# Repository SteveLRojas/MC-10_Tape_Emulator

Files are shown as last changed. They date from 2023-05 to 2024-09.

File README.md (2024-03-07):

# MC-10_Tape_Emulator
Unified HW and SW repository for the TRS-80 MC-10 tape emulator project.

## Dev Plan (USB Lib/FATFS)
✅- Get the STM to compile, 
- investigate funcs on top of in/out/transact to see how to use them to accomplish various operations
- Try to enumerate?
- Build bulk-only stuff?
- Implement SCSI stuff using bulk-only?
- ...??
- Glue functions?

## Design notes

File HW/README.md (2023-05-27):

# MC-10_Tape_Drive_PCB
EAGLE project for the MC-10 tape drive emulator PCB

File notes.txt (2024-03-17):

HAL: Hardware Abstraction Layer
HCD: USB Host Controller Driver
NVIC: Nested Vectored Interrupt Controller
RCC: Reset and Clock Controller
URB: USB Request Block

The WCH provided USB mass storage code uses a precompiled, not documented library (the Terrible Library). It must not be used. ST provides nice USB host examples for their microcontrollers, we will use that instead.

The ST provided USB mass storage code uses state machines for efficient, non blocking USB communication. Nice. But it requires the low level USB driver to also have such non-blocking functions. Sadly the WCH provided USB driver is Trash and provides only blocking functions (it does not even use interrupts).

The next step is to rewrite the low level driver based on the ST provided code and WCH datasheets.

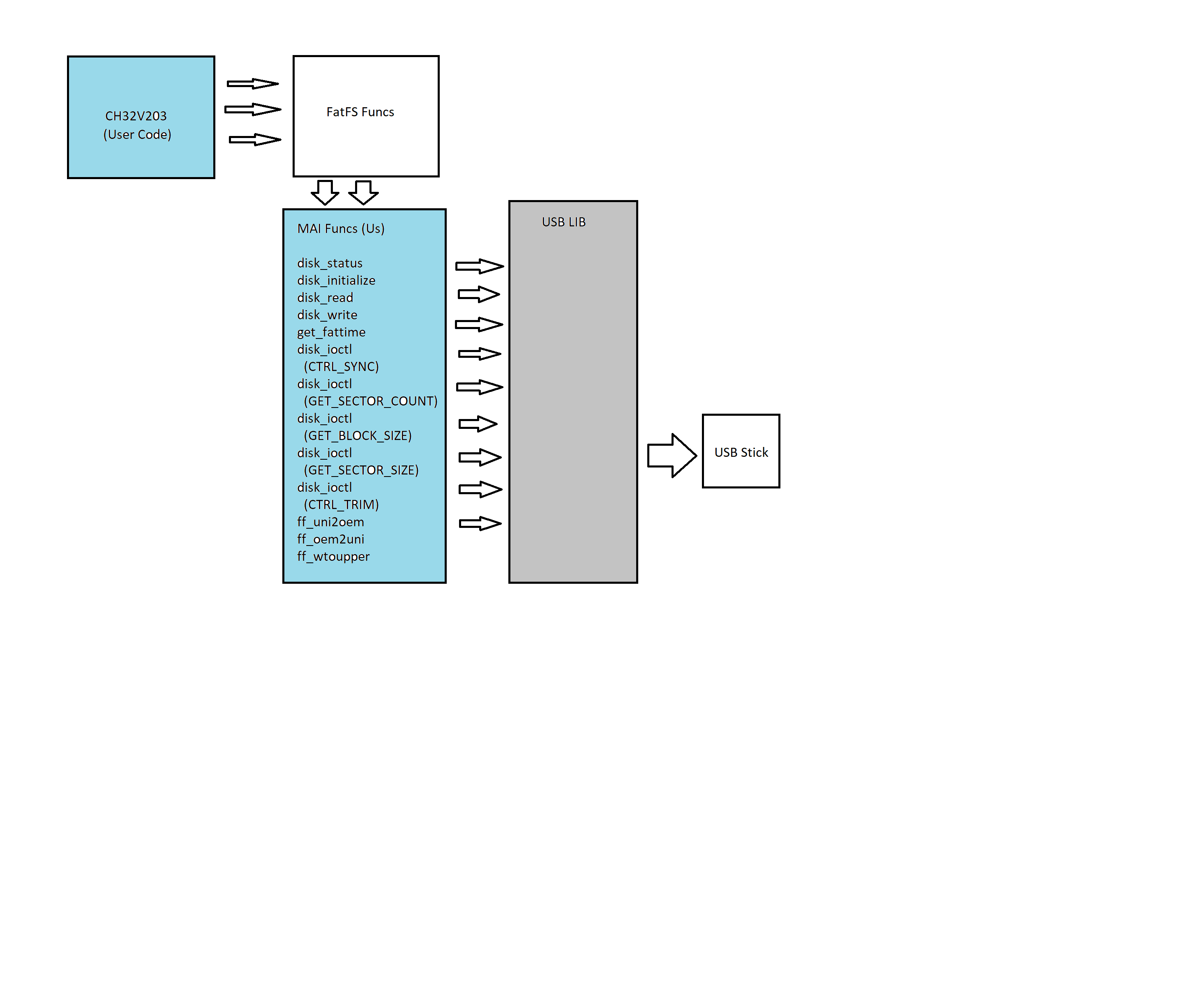
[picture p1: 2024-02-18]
USB-FS-Design.png

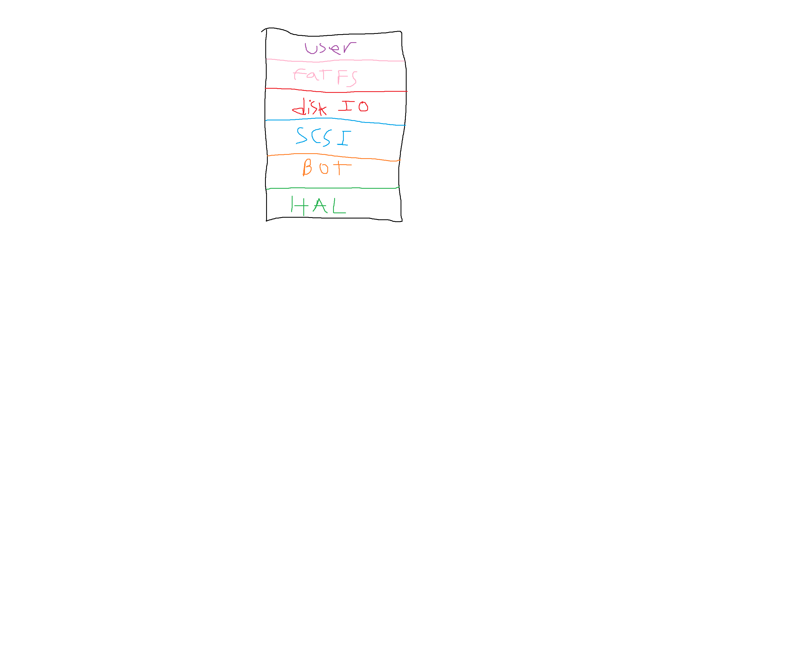
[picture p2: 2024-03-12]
udisk_stack.png

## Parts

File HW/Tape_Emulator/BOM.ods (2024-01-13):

Part | #Needed | #Owned | Satisfied? | Location
CH32V203C8T6 | 1 | 9 | TRUE | Box 6
CH376S | 1 | 1 | TRUE | Project Box
CH340G | 1 | 7 | TRUE | Box 6
3.5mm Audio Jack | 4 | 10 | TRUE | Connectors Box
Resistor 510 Ohm | 2 | 20 | TRUE | Project Box
Resistor 10K | 9 | 17 | TRUE | Project Box
Resistor 1K | 10 | 20 | TRUE | Project Box
Resistor 5K6 | 1 | 15 | TRUE | Project Box
Resistor 5K1 | 4 | 1000 | TRUE | Project Box
Resistor 470 | 2 | 20 | TRUE | Project Box
Resistor 10K Trimmer | 1 | 7 | TRUE | Project Box
Capacitor 106 (1206) | 7 | 1 | FALSE | Project Box
Capacitor 20p | 6 | 32 | TRUE | Project Box
Capacitor 104 | 14 | 200 | TRUE | Project Box
Capacitor 105 (0805) | 1 | 9 | TRUE | Box 7
ZMM2V2 | 3 | 400 | TRUE | Project Box
LMV321 (OpAmp) | 1 | 50 | TRUE | Project Box
74LVC1G17 | 2 | 14 | TRUE | Project Box
PMBT3904 | 3 | 3000 | TRUE | PMBT Box
LED (Orange) | 2 | 26 | TRUE | Project Box
Pin Header (M) 1x3 | 2 | 10 | TRUE | Connectors Box
Pin Header (F) 1x16 | 1 | 2 | TRUE | Project Box
Connector USBA | 2 | 10 | TRUE | Connectors Box
Connector USBC | 2 | 8 | TRUE
Crystal 8MHz | 1 | 10 | TRUE | Crystal Box
Crystal 12MHz | 2 | 10 | TRUE | Crystal Box
NXS0104PWJ | 3 | 5 | TRUE | Box 6
AMS1117-3.3 | 1 | 5 | TRUE | Voltage Regulator Box
25LC512T-I_SN | 1 | 2 | TRUE | Project Box
LL3301NF065QG | 5 | 15 | TRUE | Project Box
LCD 20x4 | 1 | 0 | FALSE | Display Box

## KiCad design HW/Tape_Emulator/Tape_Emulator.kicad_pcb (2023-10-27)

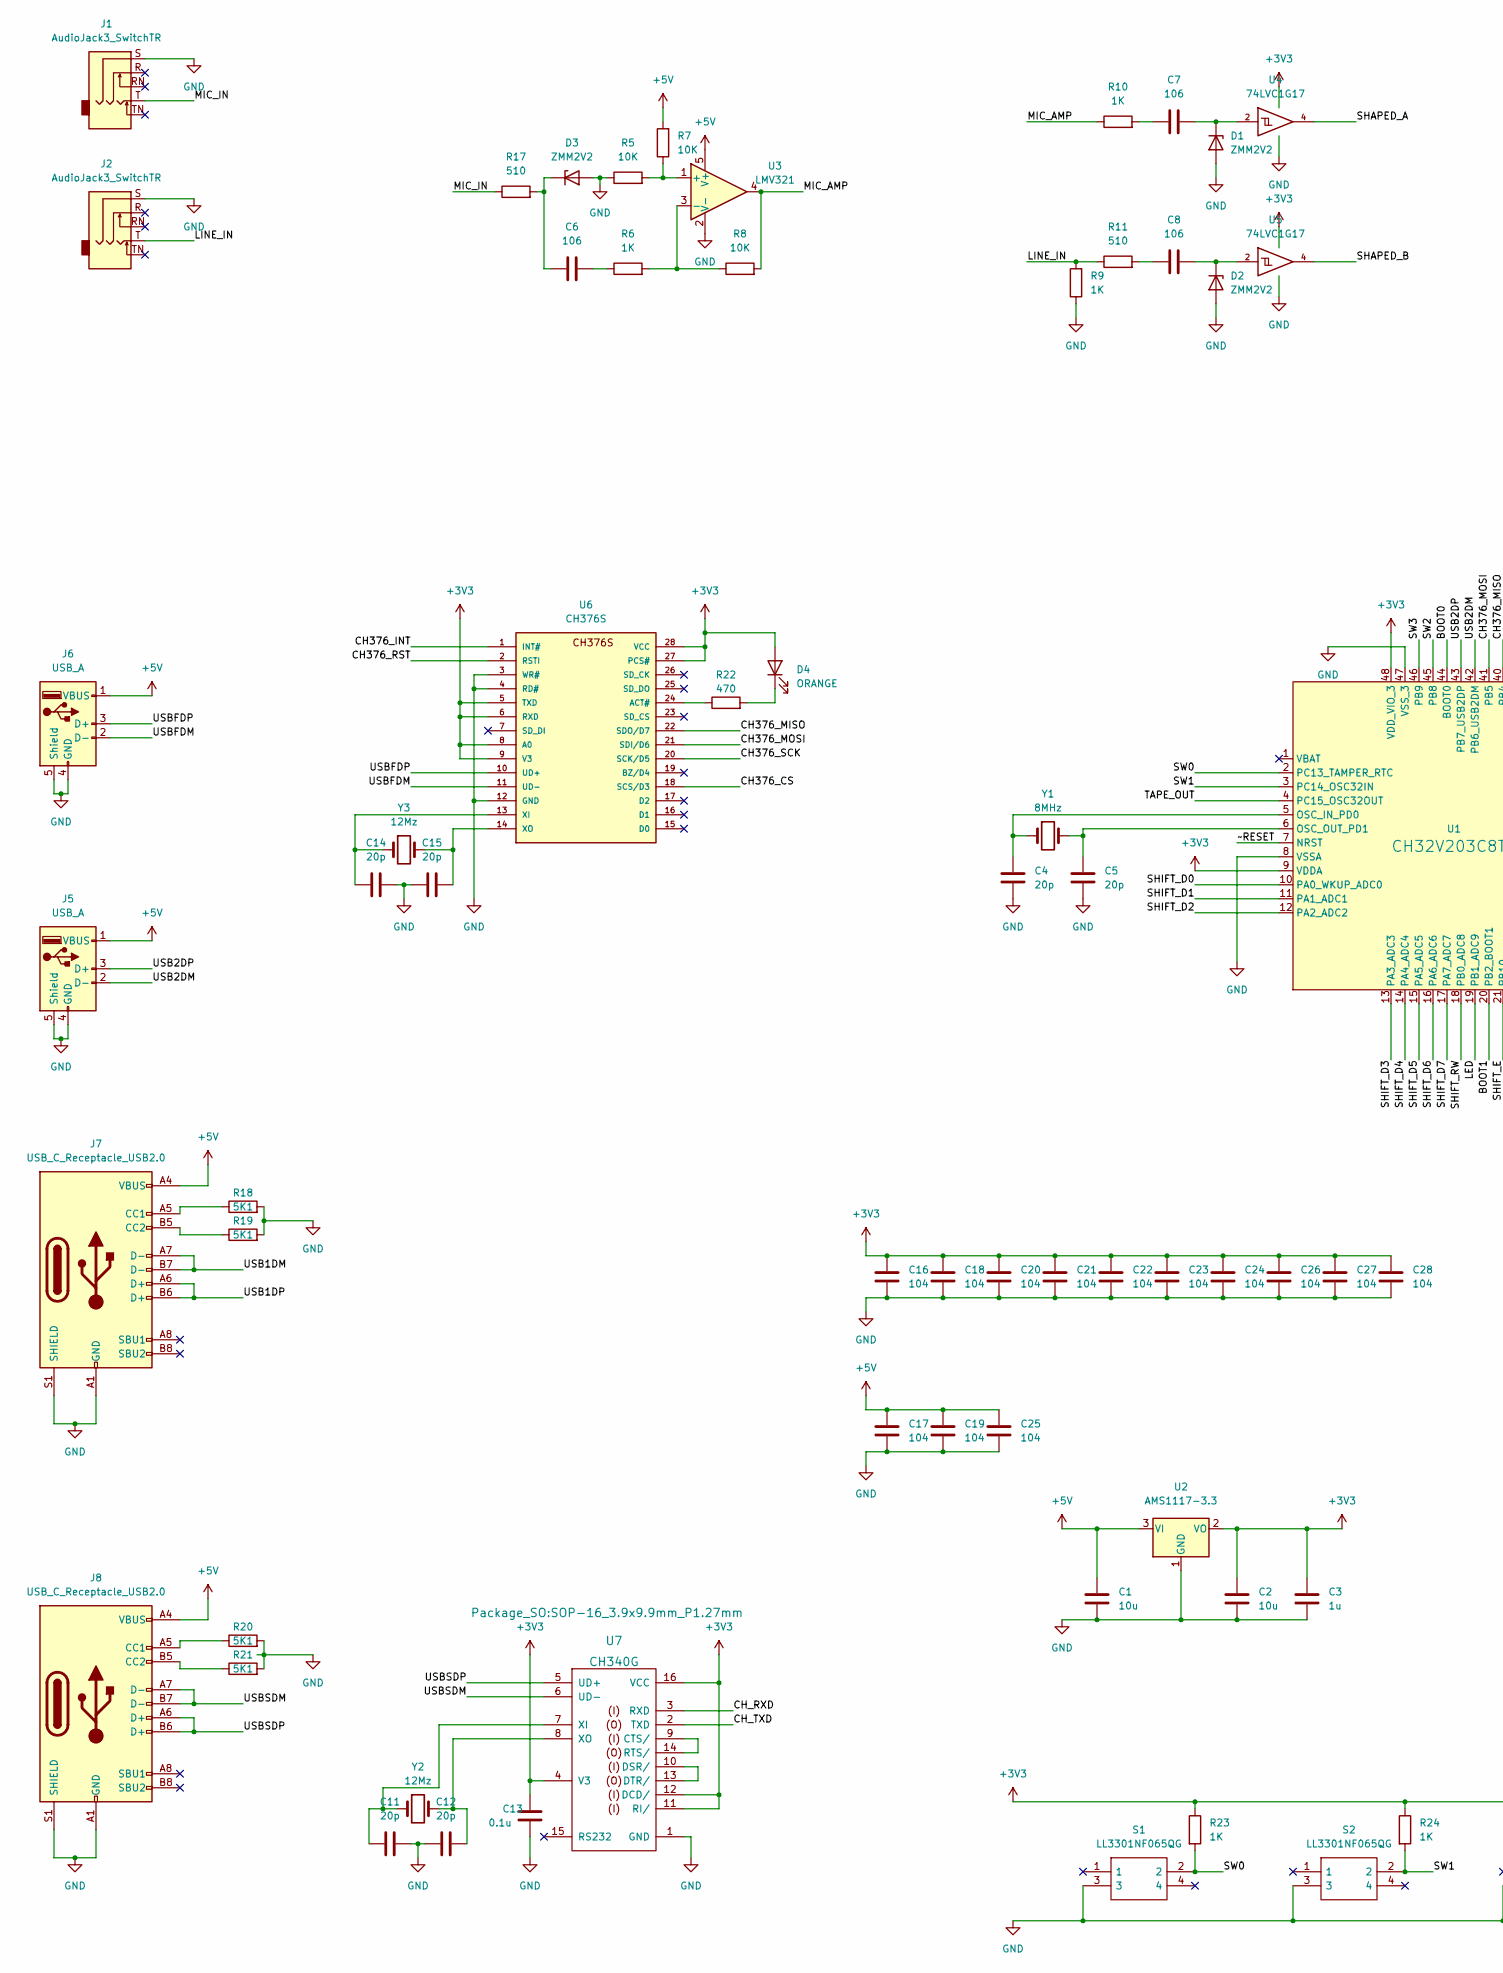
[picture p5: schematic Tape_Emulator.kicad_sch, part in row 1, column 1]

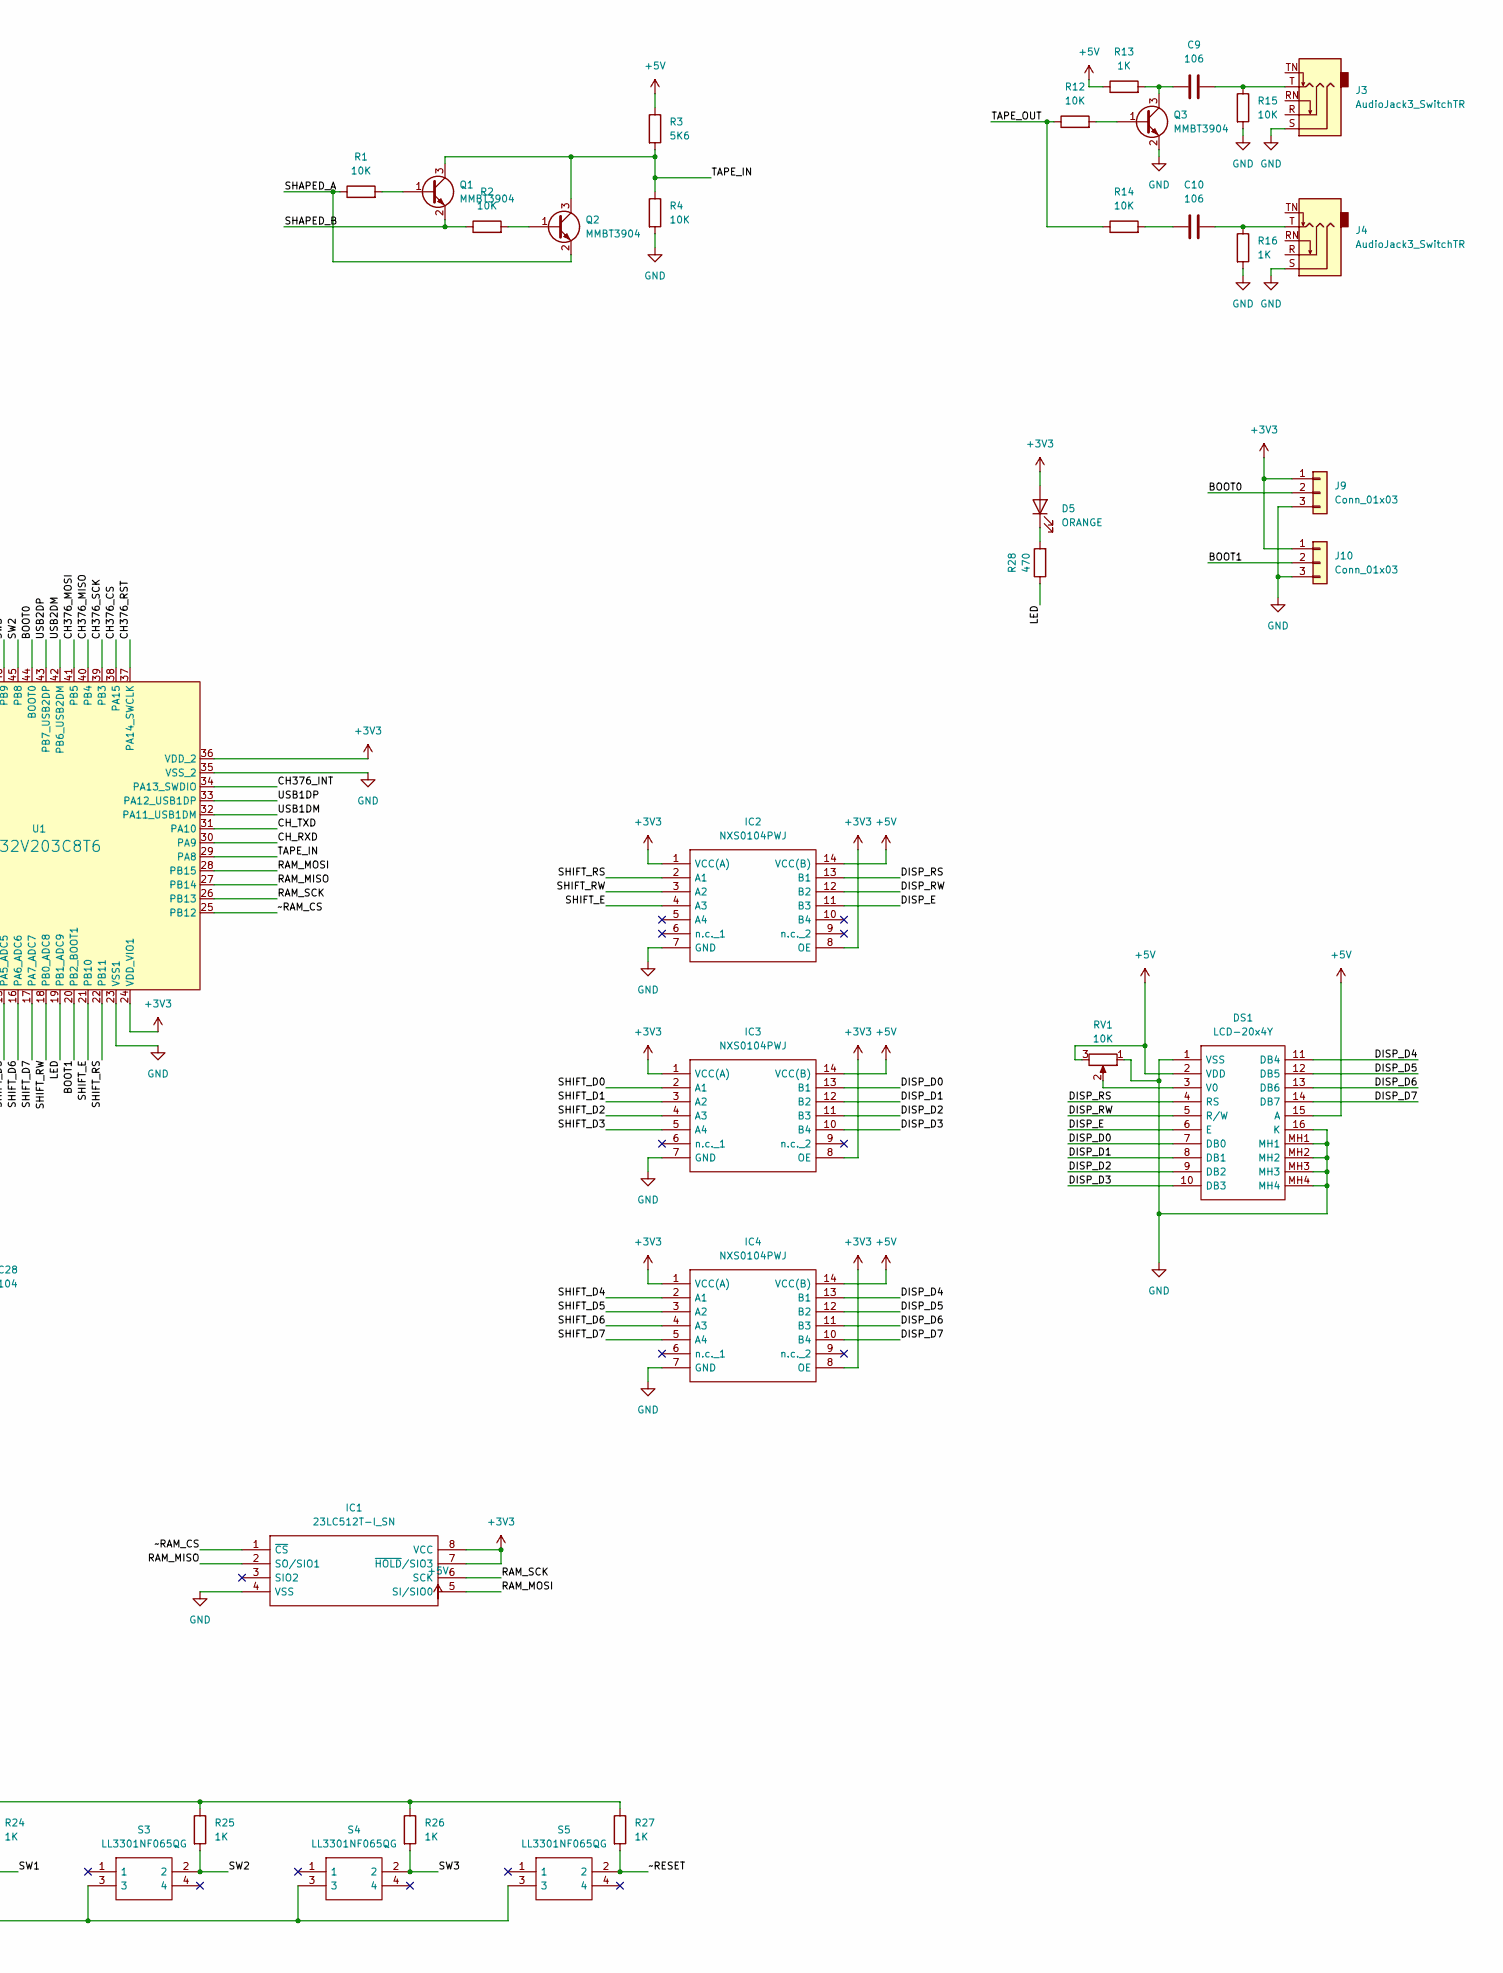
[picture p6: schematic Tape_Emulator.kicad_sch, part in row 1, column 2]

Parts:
C1, C2: 10u; C_1206_3216Metric
C3: 1u; C_0805_2012Metric
C4, C5, C11, C12, C14, C15: 20p; C_0805_2012Metric
C6, C7, C8, C9, C10: 106; C_1206_3216Metric
C13: 0.1u; C_0805_2012Metric
C16, C17, C18, C19, C20, C21, C22, C23, C24, C25, C26, C27, C28: 104; C_0805_2012Metric
D1, D2, D3: ZMM2V2; D_MiniMELF
D4, D5: ORANGE; LED_0805_2012Metric
DS1: LCD-20x4Y; LCD20x4Y; Mouser Part Number 992-LCD-20X4Y
IC1: 23LC512T-I_SN; SOIC127P600X175-8N; Mouser Part Number 579-23LC512T-I/SN
IC2, IC3, IC4: NXS0104PWJ; SOP65P640X110-14N; Mouser Part Number 771-NXS0104PWJ
J1, J2, J3, J4: AudioJack3_SwitchTR; Jack_3.5mm_CUI_SJ1-3525N_Horizontal
J5, J6: USB_A; USB_A_CONNFLY_DS1095-WNR0
J7, J8: USB_C_Receptacle_USB2.0; USB_C_Receptacle_HRO_TYPE-C-31-M-12
J9, J10: Conn_01x03; PinHeader_1x03_P2.54mm_Vertical
Q1, Q2, Q3: MMBT3904; SOT-23
R1, R2, R4, R5, R7, R8, R12, R14, R15: 10K; R_0805_2012Metric
R3: 5K6; R_0805_2012Metric
R6, R9, R10, R13, R16, R23, R24, R25, R26, R27: 1K; R_0805_2012Metric
R11, R17: 510; R_0805_2012Metric
R18, R19, R20, R21: 5K1; R_0805_2012Metric
R22, R28: 470; R_0805_2012Metric
RV1: 10K; Potentiometer_Runtron_RM-065_Vertical
S1, S2, S3, S4, S5: LL3301NF065QG; Mouser Part Number 612-LL3301NF065QG
U1: CH32V203C8T6; CH32V203C8T6_LQFP-48_7x7mm_P0.5mm
U2: AMS1117-3.3; SOT-223-3_TabPin2
U3: LMV321; SOT-23-5
U4, U5: 74LVC1G17; SOT-23-5
U6: CH376S; SOP28
U7: CH340G; SOP-16_3.9x9.9mm_P1.27mm
Y1: 8MHz; Crystal_HC49-4H_Vertical
Y2, Y3: 12Mz; Crystal_HC49-U_Vertical

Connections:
+3V3: C2.1, C3.1, C13.1, C16.1, C18.1, C20.1, C21.1, C22.1, C23.1, C24.1, C26.1, C27.1, C28.1, D4.2 (A), D5.2 (A), IC1.7 (~HOLD/SIO3), IC1.8 (VCC), IC2.1 (VCC(A)), IC2.8 (OE), IC3.1 (VCC(A)), IC3.8 (OE), IC4.1 (VCC(A)), IC4.8 (OE), J9.1, J10.1, R23.1, R24.1, R25.1, R26.1, R27.1, U1.9 (VDDA), U1.24 (VDD_VIO1), U1.36 (VDD_2), U1.48 (VDD_VIO_3), U2.2 (VO), U4.5 (VCC), U5.5 (VCC), U6.5 (TXD), U6.6 (RXD), U6.8 (A0), U6.9 (V3), U6.27 (PCS#), U6.28 (VCC), U7.4 (V3), U7.11 (RI/), U7.12 (DCD/), U7.16 (VCC)
+5V: C1.1, C17.1, C19.1, C25.1, DS1.2 (VDD), DS1.15 (A), IC2.14 (VCC(B)), IC3.14 (VCC(B)), IC4.14 (VCC(B)), J5.1 (VBUS), J6.1 (VBUS), J7.A4 (VBUS), J7.A9 (VBUS), J7.B4 (VBUS), J7.B9 (VBUS), J8.A4 (VBUS), J8.A9 (VBUS), J8.B4 (VBUS), J8.B9 (VBUS), R3.1, R7.2, R13.1, RV1.3, U2.3 (VI), U3.5 (V+)
/BOOT0: J9.2, U1.44 (BOOT0)
/BOOT1: J10.2, U1.20 (PB2_BOOT1)
/CH376_CS: U1.38 (PA15), U6.18 (SCS/D3)
/CH376_INT: U1.34 (PA13_SWDIO), U6.1 (INT#)
/CH376_MISO: U1.40 (PB4), U6.22 (SDO/D7)
/CH376_MOSI: U1.41 (PB5), U6.21 (SDI/D6)
/CH376_RST: U1.37 (PA14_SWCLK), U6.2 (RSTI)
/CH376_SCK: U1.39 (PB3), U6.20 (SCK/D5)
/CH_RXD: U1.30 (PA9), U7.3 (RXD)
/CH_TXD: U1.31 (PA10), U7.2 (TXD)
/DISP_D0: DS1.7 (DB0), IC3.13 (B1)
/DISP_D1: DS1.8 (DB1), IC3.12 (B2)
/DISP_D2: DS1.9 (DB2), IC3.11 (B3)
/DISP_D3: DS1.10 (DB3), IC3.10 (B4)
/DISP_D4: DS1.11 (DB4), IC4.13 (B1)
/DISP_D5: DS1.12 (DB5), IC4.12 (B2)
/DISP_D6: DS1.13 (DB6), IC4.11 (B3)
/DISP_D7: DS1.14 (DB7), IC4.10 (B4)
/DISP_E: DS1.6 (E), IC2.11 (B3)
/DISP_RS: DS1.4 (RS), IC2.13 (B1)
/DISP_RW: DS1.5 (R/W), IC2.12 (B2)
/LED: R28.1, U1.19 (PB1_ADC9)
/LINE_IN: J2.T, R9.2, R11.1
/MIC_AMP: R8.2, R10.1, U3.4
/MIC_IN: J1.T, R17.1
/RAM_MISO: IC1.2 (SO/SIO1), U1.27 (PB14)
/RAM_MOSI: IC1.5 (SI/SIO0), U1.28 (PB15)
/RAM_SCK: IC1.6 (SCK), U1.26 (PB13)
/SHAPED_A: Q2.2 (E), R1.1, U4.4
/SHAPED_B: Q1.2 (E), R2.1, U5.4
/SHIFT_D0: IC3.2 (A1), U1.10 (PA0_WKUP_ADC0)
/SHIFT_D1: IC3.3 (A2), U1.11 (PA1_ADC1)
/SHIFT_D2: IC3.4 (A3), U1.12 (PA2_ADC2)
/SHIFT_D3: IC3.5 (A4), U1.13 (PA3_ADC3)
/SHIFT_D4: IC4.2 (A1), U1.14 (PA4_ADC4)
/SHIFT_D5: IC4.3 (A2), U1.15 (PA5_ADC5)
/SHIFT_D6: IC4.4 (A3), U1.16 (PA6_ADC6)
/SHIFT_D7: IC4.5 (A4), U1.17 (PA7_ADC7)
/SHIFT_E: IC2.4 (A3), U1.21 (PB10)
/SHIFT_RS: IC2.2 (A1), U1.22 (PB11)
/SHIFT_RW: IC2.3 (A2), U1.18 (PB0_ADC8)
/SW0: R23.2, S1.2, U1.2 (PC13_TAMPER_RTC)
/SW1: R24.2, S2.2, U1.3 (PC14_OSC32IN)
/SW2: R25.2, S3.2, U1.45 (PB8)
/SW3: R26.2, S4.2, U1.46 (PB9)
/TAPE_IN: Q1.3 (C), Q2.3 (C), R3.2, R4.1, U1.29 (PA8)
/TAPE_OUT: R12.1, R14.1, U1.4 (PC15_OSC32OUT)
/USB1DM: J7.A7 (D-), J7.B7 (D-), U1.32 (PA11_USB1DM)
/USB1DP: J7.A6 (D+), J7.B6 (D+), U1.33 (PA12_USB1DP)
/USB2DM: J5.2 (D-), U1.42 (PB6_USB2DM)
/USB2DP: J5.3 (D+), U1.43 (PB7_USB2DP)
/USBFDM: J6.2 (D-), U6.11 (UD-)
/USBFDP: J6.3 (D+), U6.10 (UD+)
/USBSDM: J8.A7 (D-), J8.B7 (D-), U7.6 (UD-)
/USBSDP: J8.A6 (D+), J8.B6 (D+), U7.5 (UD+)
/~RAM_CS: IC1.1 (~CS), U1.25 (PB12)
/~RESET: R27.2, S5.2, U1.7 (NRST)
GND: C1.2, C2.2, C3.2, C4.2, C5.2, C11.2, C12.1, C13.2, C14.2, C15.1, C16.2, C17.2, C18.2, C19.2, C20.2, C21.2, C22.2, C23.2, C24.2, C25.2, C26.2, C27.2, C28.2, D1.2 (A), D2.2 (A), D3.2 (A), DS1.1 (VSS), DS1.16 (K), DS1.MH1, DS1.MH2, DS1.MH3, DS1.MH4, IC1.4 (VSS), IC2.7 (GND), IC3.7 (GND), IC4.7 (GND), J1.S, J2.S, J3.S, J4.S, J5.4 (GND), J5.5 (Shield), J6.4 (GND), J6.5 (Shield), J7.A1 (GND), J7.A12 (GND), J7.B1 (GND), J7.B12 (GND), J7.S1 (SHIELD), J8.A1 (GND), J8.A12 (GND), J8.B1 (GND), J8.B12 (GND), J8.S1 (SHIELD), J9.3, J10.3, Q3.2 (E), R4.2, R5.1, R9.1, R15.2, R16.2, R18.2, R19.2, R20.2, R21.2, RV1.1, S1.3, S2.3, S3.3, S4.3, S5.3, U1.8 (VSSA), U1.23 (VSS1), U1.35 (VSS_2), U1.47 (VSS_3), U2.1 (GND), U3.2 (V-), U4.3 (GND), U5.3 (GND), U6.3 (WR#), U6.4 (RD#), U6.12 (GND), U7.1 (GND)
unnamed: C4.1, U1.5 (OSC_IN_PD0), Y1.1
unnamed: C5.1, U1.6 (OSC_OUT_PD1), Y1.2
unnamed: C6.1, D3.1 (K), R17.2
unnamed: C6.2, R6.1
unnamed: C7.1, R10.2
unnamed: C7.2, D1.1 (K), U4.2
unnamed: C8.1, R11.2
unnamed: C8.2, D2.1 (K), U5.2
unnamed: C9.1, Q3.3 (C), R13.2
unnamed: C9.2, J3.T, R15.1
unnamed: C10.1, R14.2
unnamed: C10.2, J4.T, R16.1
unnamed: C11.1, U7.7 (XI), Y2.1
unnamed: C12.2, U7.8 (XO), Y2.2
unnamed: C14.1, U6.13 (XI), Y3.1
unnamed: C15.2, U6.14 (XO), Y3.2
unnamed: D4.1 (K), R22.2
unnamed: D5.1 (K), R28.2
unnamed: DS1.3 (V0), RV1.2
unnamed: J7.A5 (CC1), R18.1
unnamed: J7.B5 (CC2), R19.1
unnamed: J8.A5 (CC1), R20.1
unnamed: J8.B5 (CC2), R21.1
unnamed: Q1.1 (B), R1.2
unnamed: Q2.1 (B), R2.2
unnamed: Q3.1 (B), R12.2
unnamed: R5.2, R7.1, U3.1 (+)
unnamed: R6.2, R8.1, U3.3 (-)
unnamed: R22.1, U6.24 (ACT#)
unnamed: U7.10 (DSR/), U7.13 (DTR/)
unnamed: U7.9 (CTS/), U7.14 (RTS/)

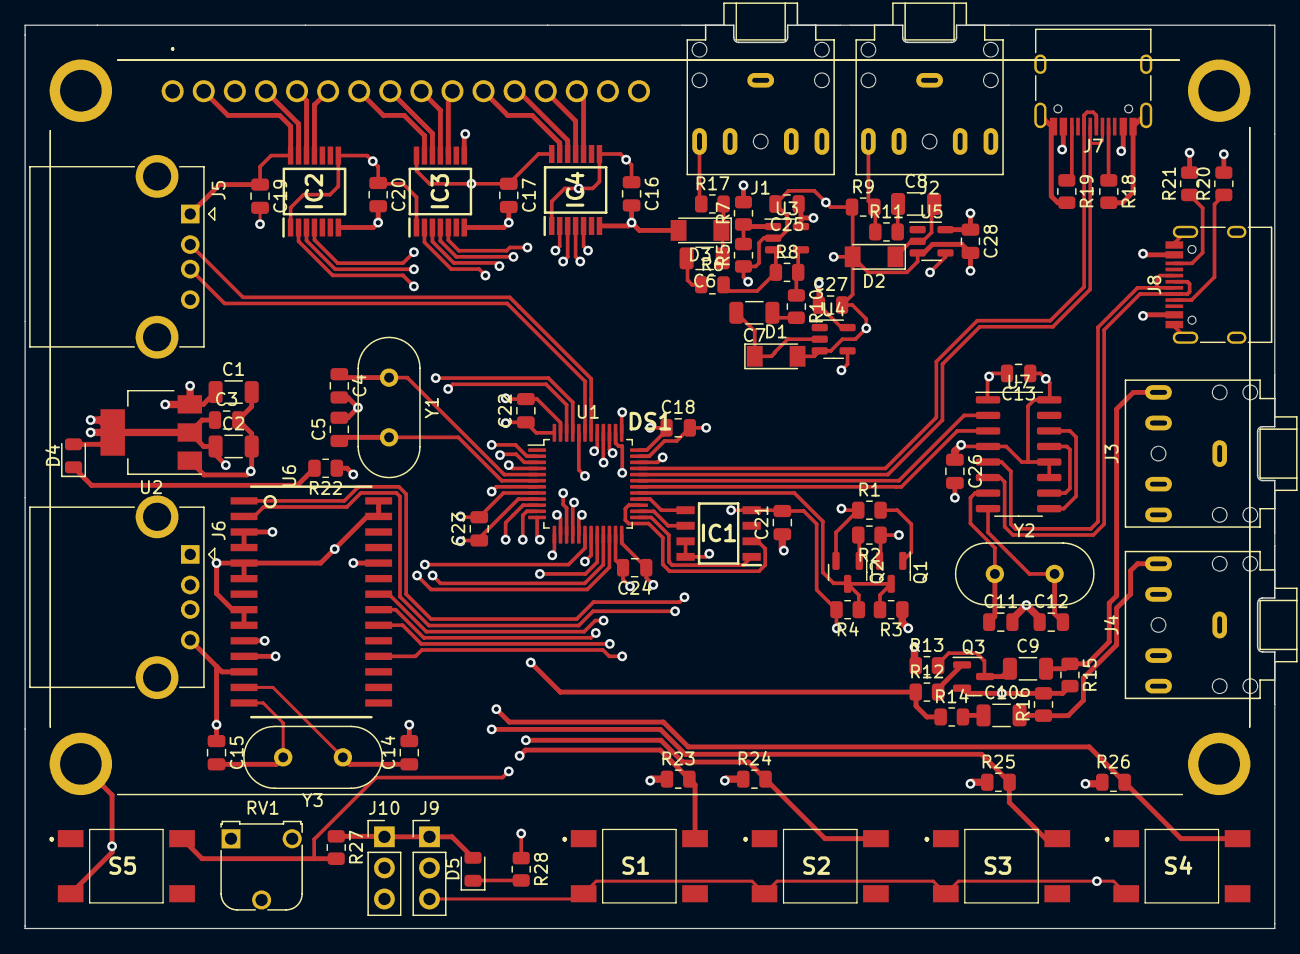
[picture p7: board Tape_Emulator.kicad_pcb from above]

Board: 4 copper layers, 102.1 x 73.8 mm, 95 parts (0 on the bottom side), 91 nets.

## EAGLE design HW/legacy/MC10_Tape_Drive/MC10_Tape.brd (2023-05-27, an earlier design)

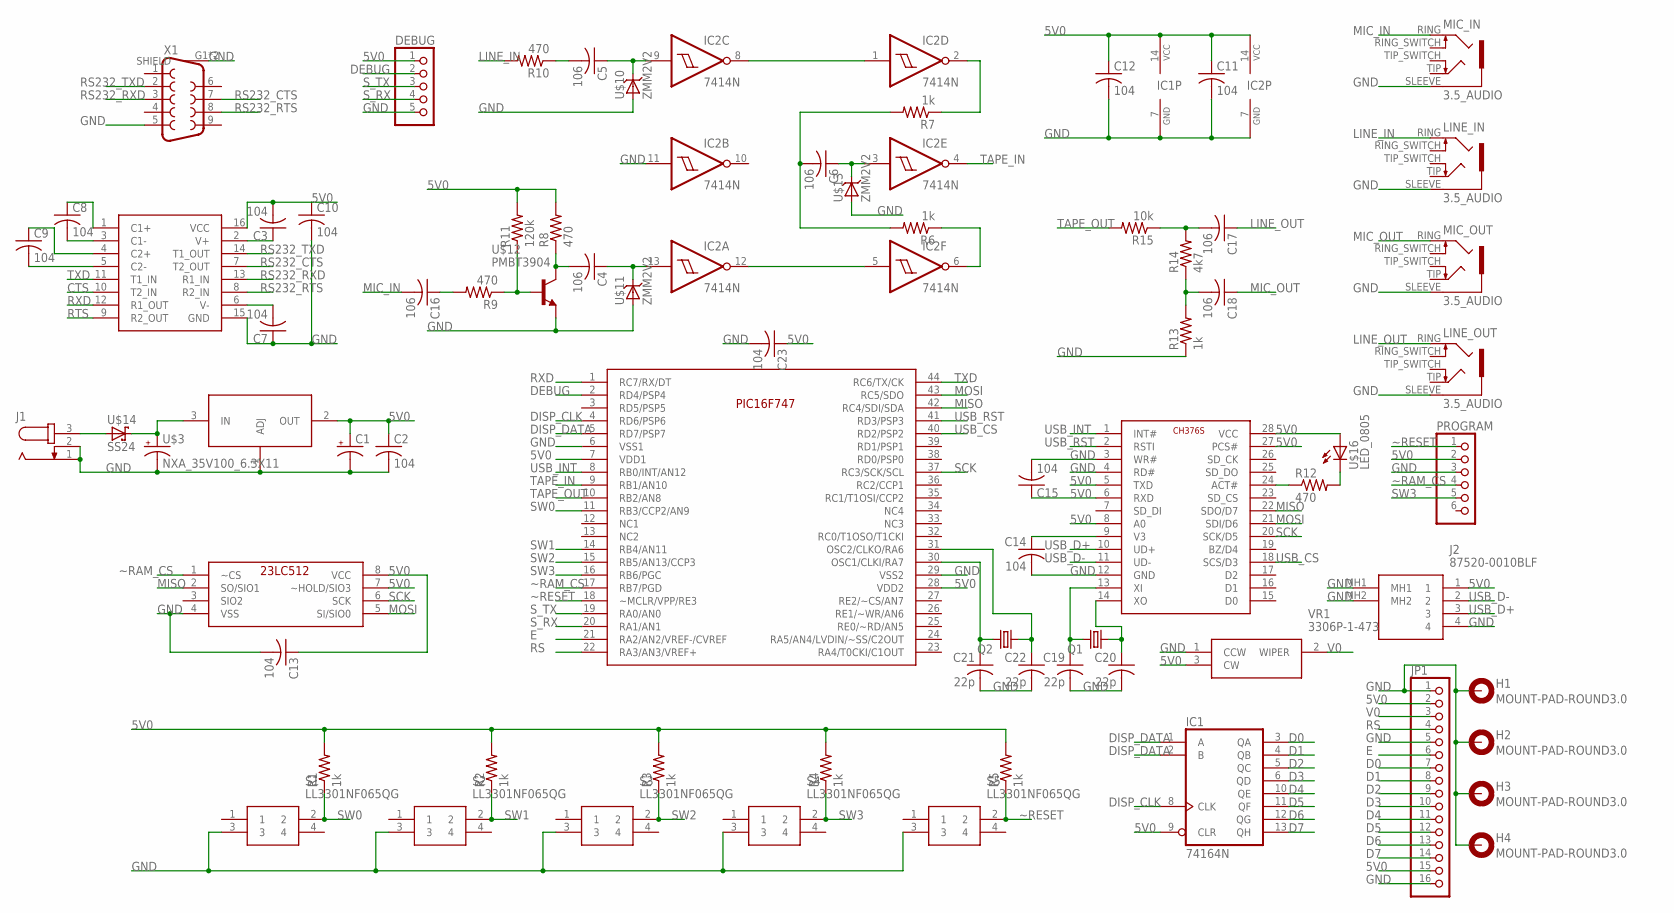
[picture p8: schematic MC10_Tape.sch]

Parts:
C1: CPOL-USUD-6,3X5,8; UD-6,3X5,8_NICHICON
C2, C3, C7, C8, C9, C10, C11, C12, C13, C14, C15, C23: 104; C0805
C4, C5, C6, C16, C17, C18: 106; C1206
C19, C20, C21, C22: 22p; C0805
DEBUG: PINHD-1X5; 1X05
H1, H2, H3, H4: MOUNT-PAD-ROUND3.0; 3,0-PAD
IC1: 74164N; DIL14
IC2: 7414N; DIL14
J1: JACK-PLUG0; SPC4077
J2: 87520-0010BLF; 875200010BLF
JP1: PINHD-1X16; 1X16
LINE_IN: 3.5_AUDIO
LINE_OUT: 3.5_AUDIO
MIC_IN: 3.5_AUDIO
MIC_OUT: 3.5_AUDIO
PROGRAM: PINHD-1X6; 1X06
Q1, Q2: CRYSTALHC49S; HC49/S
R1, R2, R3, R4, R5, R6, R7, R13: 1k; M0805
R8, R9, R10, R12: 470; M0805
R11: 120k; M0805
R14: 4k7; M0805
R15: 10k; M0805
S1, S2, S3, S4, S5: LL3301NF065QG
U$1: PIC16F747-IPT; TQFP44
U$2: LM1086; D2PACK
U$3: NXA_35V100_6.3X11
U$4: 23LC512T-ISN; SO08
U$9: SP232; SOP16
U$10, U$11, U$13: ZMM2V2; SOD80C
U$12: PMBT3904; SOT23
U$14: SS24; SMA-DO214AC
U$15: CH376S; SOP28
U$16: LED_0805; CHIP-LED0805
VR1: 3306P-1-473; 3306P1104
X1: F09HP

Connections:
5V0: C1.+, C2.1, C3.2, C10.1, C11.1, C12.1, C13.1, C15.1, C23.1, DEBUG.1, IC1.9 (CLR), IC1.14 (VCC), IC2.14 (VCC), J2.1, JP1.2, JP1.15, PROGRAM.2, R1.2, R2.2, R3.2, R4.2, R5.2, R8.2, R11.2, U$1.7 (VDD1), U$1.28 (VDD2), U$2.2 (OUT), U$4.7 (~HOLD/SIO3), U$4.8 (VCC), U$9.16 (VCC), U$15.5 (TXD), U$15.6 (RXD), U$15.8 (A0), U$15.27 (PCS#), U$15.28 (VCC), U$16.A, VR1.3 (CW)
CTS: U$9.10 (T2_IN)
D0: IC1.3 (QA), JP1.7
D1: IC1.4 (QB), JP1.8
D2: IC1.5 (QC), JP1.9
D3: IC1.6 (QD), JP1.10
D4: IC1.10 (QE), JP1.11
D5: IC1.11 (QF), JP1.12
D6: IC1.12 (QG), JP1.13
D7: IC1.13 (QH), JP1.14
DEBUG: DEBUG.2, U$1.2 (RD4/PSP4)
DISP_CLK: IC1.8 (CLK), U$1.4 (RD6/PSP6)
DISP_DATA: IC1.1 (A), IC1.2 (B), U$1.5 (RD7/PSP7)
E: JP1.6, U$1.21 (RA2/AN2/VREF-/CVREF)
GND: C1.-, C2.2, C7.1, C10.2, C11.2, C12.2, C13.2, C14.2, C15.2, C19.2, C20.2, C21.2, C22.2, C23.2, DEBUG.5, H1.B3,0, H2.B3,0, H3.B3,0, H4.B3,0, IC1.7 (GND), IC2.7 (GND), IC2.11 (I), J1.1, J1.2, J2.4, J2.MH1, J2.MH2, JP1.1, JP1.5, JP1.16, LINE_IN.SLEEVE, LINE_OUT.SLEEVE, MIC_IN.SLEEVE, MIC_OUT.SLEEVE, PROGRAM.3, R13.1, S1.3, S2.3, S3.3, S4.3, S5.3, U$1.6 (VSS1), U$1.29 (VSS2), U$2.1 (ADJ), U$3.P$1 (-), U$4.4 (VSS), U$9.15 (GND), U$10.A, U$11.A, U$12.2 (E), U$13.A, U$15.3 (WR#), U$15.4 (RD#), U$15.12 (GND), VR1.1 (CCW), X1.5, X1.G1 (SHIELD), X1.G2 (SHIELD)
LINE_IN: LINE_IN.RING, R10.2
LINE_OUT: C17.1, LINE_OUT.RING
MIC_IN: C16.2, MIC_IN.RING
MIC_OUT: C18.1, MIC_OUT.RING
MISO: U$1.42 (RC4/SDI/SDA), U$4.2 (SO/SIO1), U$15.22 (SDO/D7)
MOSI: U$1.43 (RC5/SDO), U$4.5 (SI/SIO0), U$15.21 (SDI/D6)
unnamed: C5.1, IC2.9 (I), U$10.C
unnamed: U$2.3 (IN), U$3.P$2 (+), U$14.K (C)
unnamed: C6.1, IC2.3 (I), U$13.C
unnamed: IC2.1 (I), IC2.8 (O)
unnamed: IC2.5 (I), IC2.12 (O)
unnamed: C14.1, U$15.9 (V3)
unnamed: C4.2, R8.1, U$12.3 (C)
unnamed: C4.1, IC2.13 (I), U$11.C
unnamed: R9.1, R11.1, U$12.1 (B)
unnamed: C17.2, R14.2, R15.1
unnamed: R12.2, U$16.C
unnamed: C16.1, R9.2
unnamed: IC2.6 (O), R6.1
unnamed: C6.2, R6.2, R7.2
unnamed: IC2.2 (O), R7.1
unnamed: C18.2, R13.2, R14.1
unnamed: C21.1, Q2.2, U$1.30 (OSC1/CLKI/RA7)
unnamed: C20.1, Q1.1, U$15.14 (XO)
unnamed: C19.1, Q1.2, U$15.13 (XI)
unnamed: C22.1, Q2.1, U$1.31 (OSC2/CLKO/RA6)
unnamed: R12.1, U$15.24 (ACT#)
unnamed: J1.3, U$14.A
unnamed: C8.2, U$9.3 (C1-)
unnamed: C8.1, U$9.1 (C1+)
unnamed: C9.2, U$9.5 (C2-)
unnamed: C9.1, U$9.4 (C2+)
unnamed: C3.1, U$9.2 (V+)
unnamed: C7.2, U$9.6 (V-)
unnamed: C5.2, R10.1
RS: JP1.4, U$1.22 (RA3/AN3/VREF+)
RS232_CTS: U$9.7 (T2_OUT), X1.7
RS232_RTS: U$9.8 (R2_IN), X1.8
RS232_RXD: U$9.13 (R1_IN), X1.3
RS232_TXD: U$9.14 (T1_OUT), X1.2
RTS: U$9.9 (R2_OUT)
RXD: U$1.1 (RC7/RX/DT), U$9.12 (R1_OUT)
SCK: U$1.37 (RC3/SCK/SCL), U$4.6 (SCK), U$15.20 (SCK/D5)
SW0: R1.1, S1.2, U$1.11 (RB3/CCP2/AN9)
SW1: R2.1, S2.2, U$1.14 (RB4/AN11)
SW2: R3.1, S3.2, U$1.15 (RB5/AN13/CCP3)
SW3: PROGRAM.5, R4.1, S4.2, U$1.16 (RB6/PGC)
S_RX: DEBUG.4, U$1.20 (RA1/AN1)
S_TX: DEBUG.3, U$1.19 (RA0/AN0)
TAPE_IN: IC2.4 (O), U$1.9 (RB1/AN10)
TAPE_OUT: R15.2, U$1.10 (RB2/AN8)
TXD: U$1.44 (RC6/TX/CK), U$9.11 (T1_IN)
USB_CS: U$1.40 (RD2/PSP2), U$15.18 (SCS/D3)
USB_D+: J2.3, U$15.10 (UD+)
USB_D-: J2.2, U$15.11 (UD-)
USB_INT: U$1.8 (RB0/INT/AN12), U$15.1 (INT#)
USB_RST: U$1.41 (RD3/PSP3), U$15.2 (RSTI)
V0: JP1.3, VR1.2 (WIPER)
~RAM_CS: PROGRAM.4, U$1.17 (RB7/PGD), U$4.1 (~CS)
~RESET: PROGRAM.1, R5.1, S5.2, U$1.18 (~MCLR/VPP/RE3)

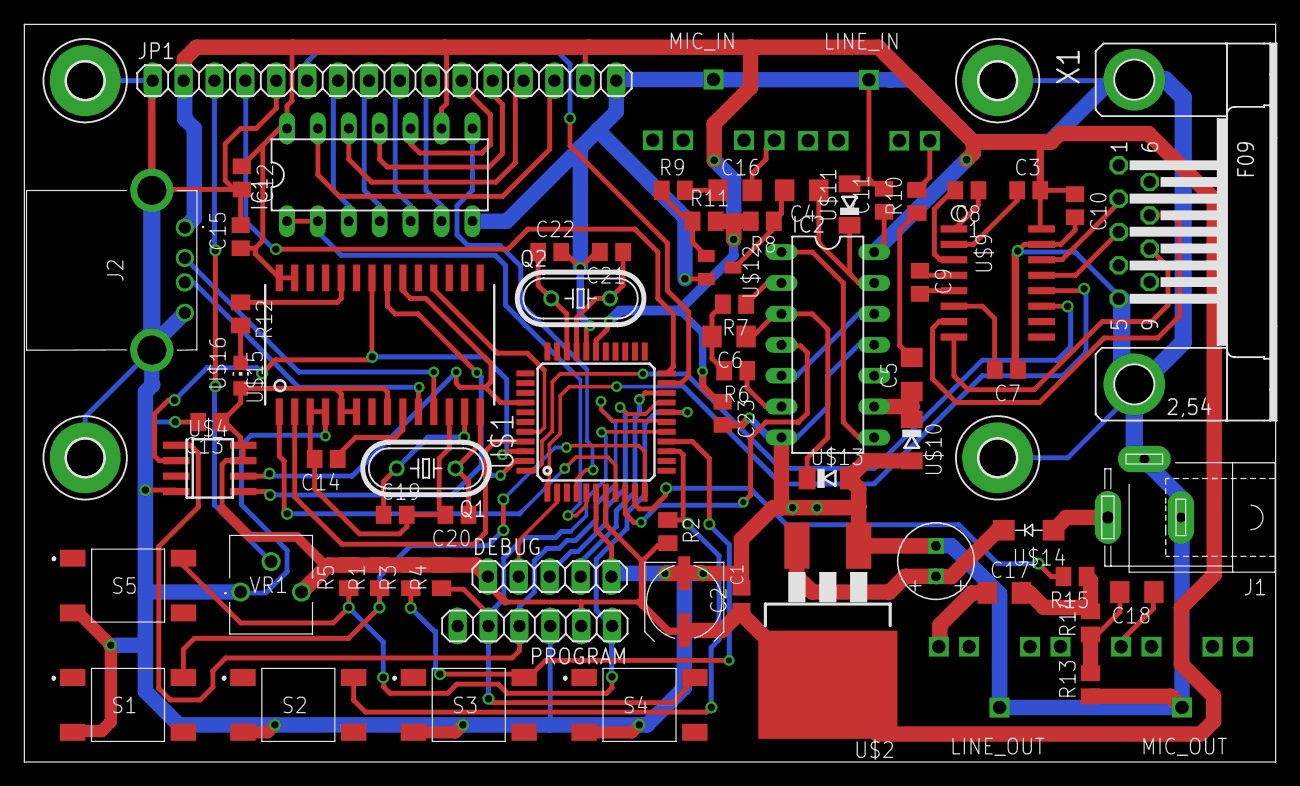
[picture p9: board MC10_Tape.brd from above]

Board: 2 copper layers, 102.8 x 60.6 mm, 74 parts (0 on the bottom side), 73 nets.

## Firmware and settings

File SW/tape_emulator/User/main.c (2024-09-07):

#include "ch32v20x.h"
#include "fifo.h"
#include "ch32v203_afio.h"
#include "ch32v203_core.h"
#include "ch32v203_gpio.h"
#include "ch32v203_rcc.h"
//#include "ch32v203_spi.h"
//#include "ch32v203_timer.h"
#include "ch32v203_uart.h"
//#include "ch32v203_usbd.h"
#include "ch32v203_usbd_cdc.h"
//#include "ch32v203_usbfsd.h"
#include "ch32v203_usbfsh.h"
//#include "pseudo_random.h"
#include "debug.h"
#include "support.h"
#include "lcd.h"
#include "usbfsh_msc_bot.h"

//Pins:
// DISP = PA0 - PA7
// TAPE_IN = PA8
// CH_RXD = PA9
// CH_TXD = PA10
// USB1DM = PA11
// USB1DP = PA12
// CH376_INT = PA13
// CH376_RST = PA14
// CH376_CS = PA15
// DISP_RW = PB0
// LED = PB1
// BOOT1 = PB2
// CH376_SCK = PB3
// CH376_MISO = PB4
// CH376_MOSI = PB5
// USB2DM = PB6
// USB2DP = PB7
// SW2 = PB8
// SW3 = PB9
// DISP_E = PB10
// DISP_RS = PB11
// RAM_CS = PB12
// RAM_SCK = PB13
// RAM_MISO = PB14
// RAM_MOSI = PB15
// SW0 = PC13
// SW1 = PC14
// TAPE_OUT = PC15

void print_bytes_as_hex(const uint8_t* source, uint8_t num_bytes)
{
	uint8_t idx;

	for(idx = 0; idx < num_bytes; ++idx)
	{
		printf("%02X: %02X\n", idx, source[idx]);
	}
}

int main(void)
{
	rcc_apb2_clk_enable(RCC_AFIOEN | RCC_IOPAEN | RCC_IOPBEN | RCC_IOPCEN | RCC_TIM1EN | RCC_SPI1EN | RCC_USART1EN);
	rcc_apb1_clk_enable(RCC_TIM2EN | RCC_USBEN);
	rcc_ahb_clk_enable(RCC_USBFS);

	gpio_set_mode(GPIOA, GPIO_DIR_SPD_OUT_50MHZ | GPIO_MODE_PP_OUT, GPIO_PIN_0 | GPIO_PIN_1 | GPIO_PIN_2 | GPIO_PIN_3 | GPIO_PIN_4 | GPIO_PIN_5 | GPIO_PIN_6 | GPIO_PIN_7 | GPIO_PIN_14 | GPIO_PIN_15);
	gpio_set_mode(GPIOA, GPIO_DIR_SPD_IN | GPIO_MODE_FLOAT_IN, GPIO_PIN_8 | GPIO_PIN_10 | GPIO_PIN_13);
	gpio_set_mode(GPIOA, GPIO_DIR_SPD_OUT_50MHZ | GPIO_MODE_AFIO_PP, GPIO_PIN_9);

	gpio_set_mode(GPIOB, GPIO_DIR_SPD_OUT_50MHZ | GPIO_MODE_PP_OUT, GPIO_PIN_0 | GPIO_PIN_1 | GPIO_PIN_10 | GPIO_PIN_11 | GPIO_PIN_12);
	gpio_set_mode(GPIOB, GPIO_DIR_SPD_IN | GPIO_MODE_FLOAT_IN, GPIO_PIN_8 | GPIO_PIN_9);

	gpio_set_mode(GPIOC, GPIO_DIR_SPD_IN | GPIO_MODE_FLOAT_IN, GPIO_PIN_13 | GPIO_PIN_14);
	gpio_set_mode(GPIOC, GPIO_DIR_SPD_OUT_2MHZ | GPIO_MODE_PP_OUT, GPIO_PIN_15);

	gpio_set_pin(GPIOA, GPIO_PIN_14);
	gpio_set_pin(GPIOB, GPIO_PIN_12);

	Delay_Init();
	uart_init(USART1, 115200);
	core_enable_irq(USART1_IRQn);

	printf("SYSCLK: %u\n", rcc_compute_sysclk_freq());
	printf("HCLK: %u\n", rcc_compute_hclk_freq());
	printf("PCLK1: %u\n", rcc_compute_pclk1_freq());
	printf("PCLK2: %u\n", rcc_compute_pclk2_freq());
	printf("ADCCLK: %u\n", rcc_compute_adcclk());

	// blink the led once
	gpio_clear_pin(GPIOB, GPIO_PIN_1);
	Delay_Ms(100);
	gpio_set_pin(GPIOB, GPIO_PIN_1);
	printf("Unicorn\n");

	cdc_init();
	cdc_set_serial_state(0x03);

	lcd_init();
	lcd_print_string("Tape Emulator");

	usbfsh_msc_bot_init();

	uint8_t button_state_prev[4];
	uint8_t connected_state_prev;
	button_state_prev[0] = gpio_read_pin(GPIOC, GPIO_PIN_13);
	button_state_prev[1] = gpio_read_pin(GPIOC, GPIO_PIN_14);
	button_state_prev[2] = gpio_read_pin(GPIOB, GPIO_PIN_8);
	button_state_prev[3] = gpio_read_pin(GPIOB, GPIO_PIN_9);
	connected_state_prev = usbfsh_port_is_attached();
	while(1)
	{
		if(!gpio_read_pin(GPIOC, GPIO_PIN_13) && button_state_prev[0])
		{
			printf("S1 Pressed\n");
			if(usbfsh_msc_bot_configure())
				printf("Configuration successful\n");
			else
				printf("Configuration failed\n");
		}
		if(!gpio_read_pin(GPIOC, GPIO_PIN_14) && button_state_prev[1])
			printf("S2 Pressed\n");
		if(!gpio_read_pin(GPIOB, GPIO_PIN_8) && button_state_prev[2])
			printf("S3 Pressed\n");
		if(!gpio_read_pin(GPIOB, GPIO_PIN_9) && button_state_prev[3])
			printf("S4 Pressed\n");

		if(usbfsh_port_is_attached() & ~connected_state_prev)
			printf("Device connected\n");
		if(~usbfsh_port_is_attached() & connected_state_prev)
			printf("Device disconnected\n");

		button_state_prev[0] = gpio_read_pin(GPIOC, GPIO_PIN_13);
		button_state_prev[1] = gpio_read_pin(GPIOC, GPIO_PIN_14);
		button_state_prev[2] = gpio_read_pin(GPIOB, GPIO_PIN_8);
		button_state_prev[3] = gpio_read_pin(GPIOB, GPIO_PIN_9);
		connected_state_prev = usbfsh_port_is_attached();

		Delay_Ms(1);
	}
}

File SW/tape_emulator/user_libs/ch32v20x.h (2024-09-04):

/********************************** (C) COPYRIGHT  *******************************
 * File Name          : ch32v20x.h
 * Author             : WCH
 * Version            : V1.0.0
 * Date               : 2021/06/06
 * Description        : CH32V20x Device Peripheral Access Layer Header File.
*********************************************************************************
* Copyright (c) 2021 Nanjing Qinheng Microelectronics Co., Ltd.
* Attention: This software (modified or not) and binary are used for 
* microcontroller manufactured by Nanjing Qinheng Microelectronics.
*******************************************************************************/
#ifndef __CH32V20x_H
#define __CH32V20x_H

#ifdef __cplusplus
extern "C" {
#endif
#include <stdint.h>

#if !defined(CH32V20x_D8W) && !defined(CH32V20x_D8) && !defined(CH32V20x_D6)
#define CH32V20x_D6              /* CH32V203F6-CH32V203F8-CH32V203G6-CH32V203G8-CH32V203K6-CH32V203K8-CH32V203C6-CH32V203C8 */
//#define CH32V20x_D8              /* CH32V203RBT6 */
//#define CH32V20x_D8W             /* CH32V208 */
#endif

/* In the following line adjust the External High Speed oscillator (HSE) Startup Timeout value */
#define HSE_STARTUP_TIMEOUT    ((uint16_t)0x1000) /* Time out for HSE start up */

#define HSI_VALUE              ((uint32_t)8000000) /* Value of the Internal oscillator in Hz */

/* Interrupt Number Definition, according to the selected device */
typedef enum IRQn
{
    /******  RISC-V Processor Exceptions Numbers *******************************************************/
    NonMaskableInt_IRQn = 2, /* 2 Non Maskable Interrupt                             */
    EXC_IRQn = 3,            /* 3 Exception Interrupt                                */
    Ecall_M_Mode_IRQn = 5,   /* 5 Ecall M Mode Interrupt                             */
    Ecall_U_Mode_IRQn = 8,   /* 8 Ecall U Mode Interrupt                             */
    Break_Point_IRQn = 9,    /* 9 Break Point Interrupt                              */
    SysTicK_IRQn = 12,       /* 12 System timer Interrupt                            */
    Software_IRQn = 14,      /* 14 software Interrupt                                */

    /******  RISC-V specific Interrupt Numbers *********************************************************/
    WWDG_IRQn = 16,            /* Window WatchDog Interrupt                            */
    PVD_IRQn = 17,             /* PVD through EXTI Line detection Interrupt            */
    TAMPER_IRQn = 18,          /* Tamper Interrupt                                     */
    RTC_IRQn = 19,             /* RTC global Interrupt                                 */
    FLASH_IRQn = 20,           /* FLASH global Interrupt                               */
    RCC_IRQn = 21,             /* RCC global Interrupt                                 */
    EXTI0_IRQn = 22,           /* EXTI Line0 Interrupt                                 */
    EXTI1_IRQn = 23,           /* EXTI Line1 Interrupt                                 */
    EXTI2_IRQn = 24,           /* EXTI Line2 Interrupt                                 */
    EXTI3_IRQn = 25,           /* EXTI Line3 Interrupt                                 */
    EXTI4_IRQn = 26,           /* EXTI Line4 Interrupt                                 */
    DMA1_Channel1_IRQn = 27,   /* DMA1 Channel 1 global Interrupt                      */
    DMA1_Channel2_IRQn = 28,   /* DMA1 Channel 2 global Interrupt                      */
    DMA1_Channel3_IRQn = 29,   /* DMA1 Channel 3 global Interrupt                      */
    DMA1_Channel4_IRQn = 30,   /* DMA1 Channel 4 global Interrupt                      */
    DMA1_Channel5_IRQn = 31,   /* DMA1 Channel 5 global Interrupt                      */
    DMA1_Channel6_IRQn = 32,   /* DMA1 Channel 6 global Interrupt                      */
    DMA1_Channel7_IRQn = 33,   /* DMA1 Channel 7 global Interrupt                      */
    ADC_IRQn = 34,             /* ADC1 and ADC2 global Interrupt                       */
    USB_HP_CAN1_TX_IRQn = 35,  /* USB Device High Priority or CAN1 TX Interrupts       */
    USB_LP_CAN1_RX0_IRQn = 36, /* USB Device Low Priority or CAN1 RX0 Interrupts       */
    CAN1_RX1_IRQn = 37,        /* CAN1 RX1 Interrupt                                   */
    CAN1_SCE_IRQn = 38,        /* CAN1 SCE Interrupt                                   */
    EXTI9_5_IRQn = 39,         /* External Line[9:5] Interrupts                        */
    TIM1_BRK_IRQn = 40,        /* TIM1 Break Interrupt                                 */
    TIM1_UP_IRQn = 41,         /* TIM1 Update Interrupt                                */
    TIM1_TRG_COM_IRQn = 42,    /* TIM1 Trigger and Commutation Interrupt               */
    TIM1_CC_IRQn = 43,         /* TIM1 Capture Compare Interrupt                       */
    TIM2_IRQn = 44,            /* TIM2 global Interrupt                                */
    TIM3_IRQn = 45,            /* TIM3 global Interrupt                                */
    TIM4_IRQn = 46,            /* TIM4 global Interrupt                                */
    I2C1_EV_IRQn = 47,         /* I2C1 Event Interrupt                                 */
    I2C1_ER_IRQn = 48,         /* I2C1 Error Interrupt                                 */
    I2C2_EV_IRQn = 49,         /* I2C2 Event Interrupt                                 */
    I2C2_ER_IRQn = 50,         /* I2C2 Error Interrupt                                 */
    SPI1_IRQn = 51,            /* SPI1 global Interrupt                                */
    SPI2_IRQn = 52,            /* SPI2 global Interrupt                                */
    USART1_IRQn = 53,          /* USART1 global Interrupt                              */
    USART2_IRQn = 54,          /* USART2 global Interrupt                              */
    USART3_IRQn = 55,          /* USART3 global Interrupt                              */
    EXTI15_10_IRQn = 56,       /* External Line[15:10] Interrupts                      */
    RTCAlarm_IRQn = 57,        /* RTC Alarm through EXTI Line Interrupt                */
    USBWakeUp_IRQn = 58,       /* USB Device WakeUp from suspend through EXTI Line Interrupt 	*/
    USBFS_IRQn = 59,           /* USBHD global Interrupt                               */
    USBFSWakeUp_IRQn = 60,     /* USB Host/Device WakeUp Interrupt                     */

#ifdef CH32V20x_D6
    UART4_IRQn = 61,         /* UART4 global Interrupt                               */
    DMA1_Channel8_IRQn = 62, /* DMA1 Channel 8 global Interrupt                      */
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

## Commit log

2023-10-27 Cleaned up project structure, added new HW
    [MC10_Tape.GBL, MC10_Tape.GBO, MC10_Tape.GBP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]
2023-11-26 Created MRS project
    [BOM.ods, Tape_Emulator.csv]
2024-01-13 Added BOM
    [BOM.ods, Tape_Emulator.csv]
2024-02-10 removed/replaced stuff from UART.c UART.h
    [cdc_serial.c, cdc_serial.h, main.c]
2024-03-27 Using LED and buttons, SCSI TestUnitReady working for most flash drives
2024-05-25 FatFs glue functions, got file read working
